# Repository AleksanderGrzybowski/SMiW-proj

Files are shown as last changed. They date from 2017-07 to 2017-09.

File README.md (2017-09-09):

# SMiW-proj
An ATmega16 based clock on steroids

This is DS1307 + ATmega based digital clock, made for Embedded Systems course. Developed on mega16 at the university (cause everyone were using mega8 for no reason), switched to mega8 later.
Includes multiplexing, I2C interfacing and buttons for setting time, brightness and other settings.

In the second version I remade it to work fully on a single 18650 battery (lasts for a week or so on a cheap cell extracted from a broken powerbank), with battery voltage monitoring. USB charger module and boost module (3.7 -> 5) are glued on the backside.

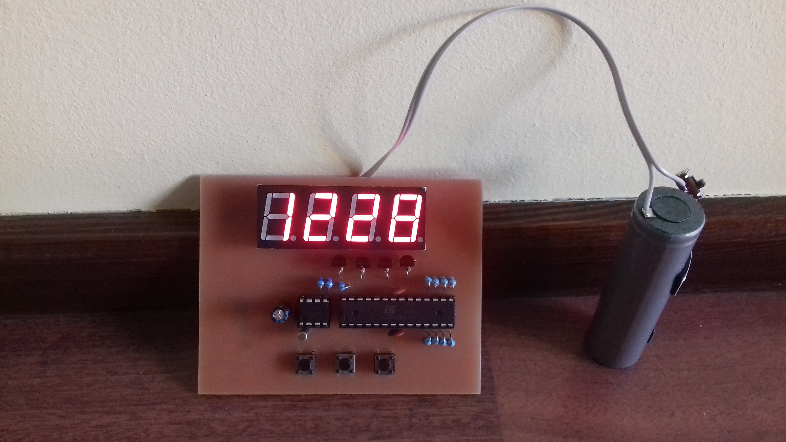
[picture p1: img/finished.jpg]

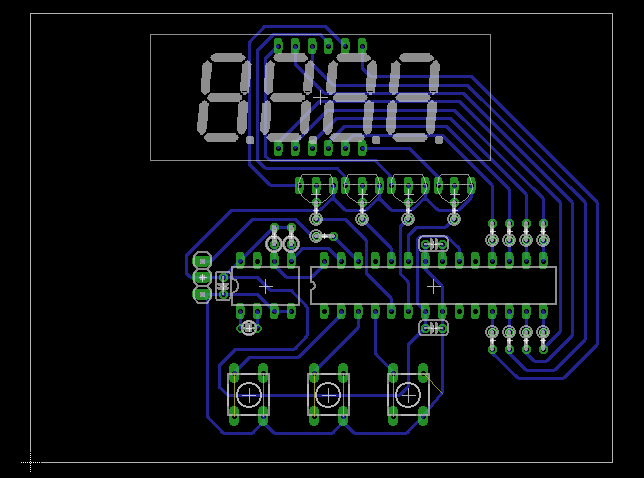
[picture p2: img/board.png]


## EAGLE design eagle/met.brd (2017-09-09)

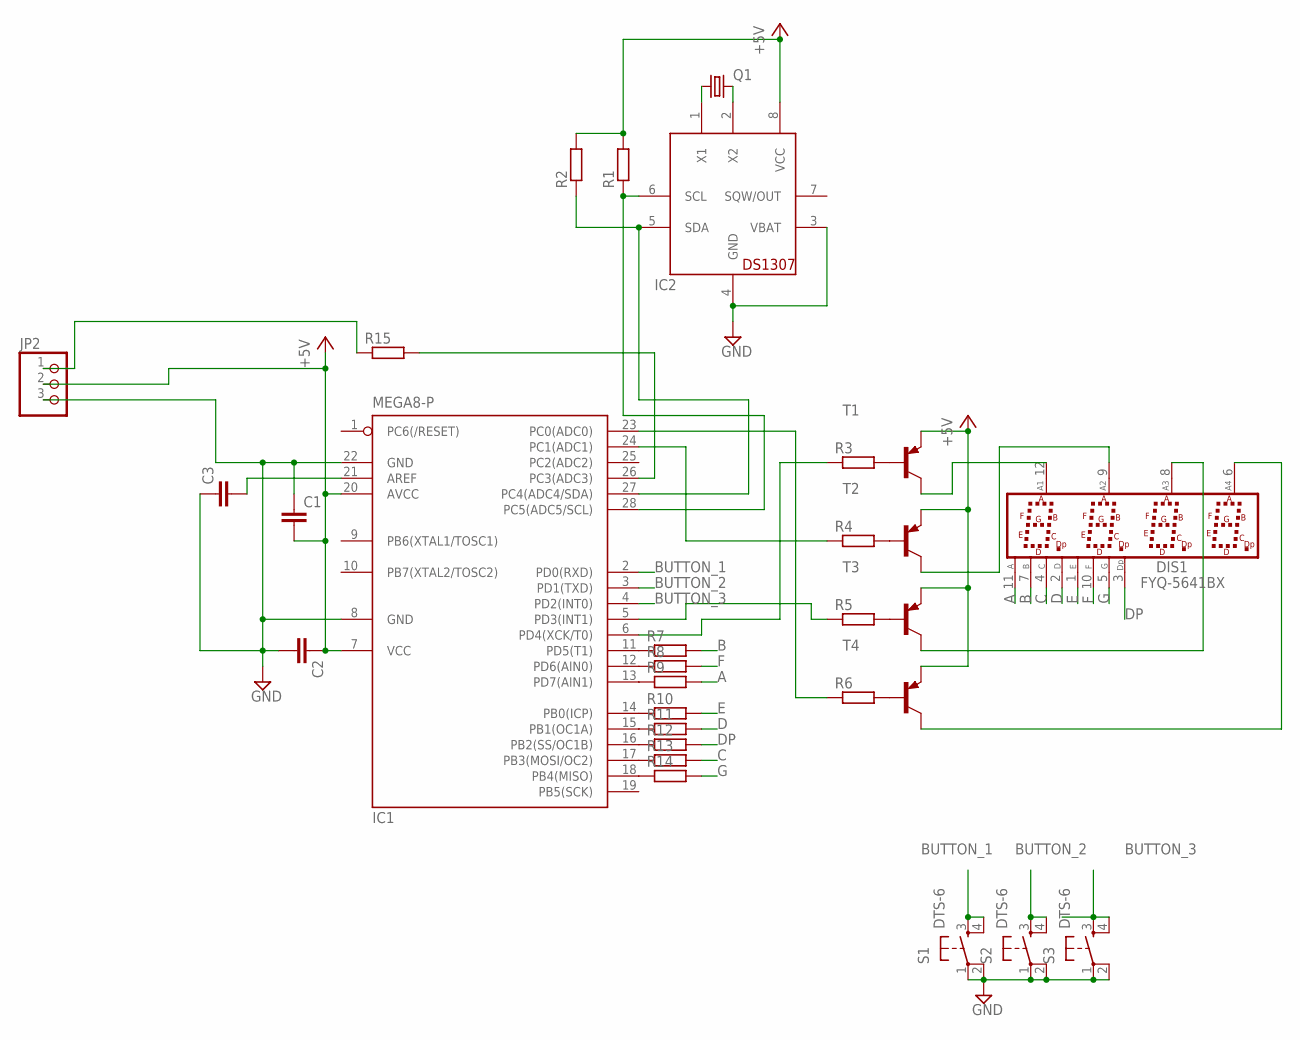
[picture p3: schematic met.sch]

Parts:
C1, C2, C3: C-EU025-024X044; C025-024X044
DIS1: FYQ-5641BX; FYQ5641
IC1: MEGA8-P; DIL28-3
IC2: DS1307; DIL08
JP2: PINHD-1X3; 1X03
Q1: CRYSTALTC26V; TC26V
R1, R2: R-EU_0207/2V; 0207/2V
R3, R4, R5, R6, R7, R8, R9, R10, R11, R12, R13, R14, R15: R-EU_0204/2V; 0204V
S1, S2, S3: DTS-6
T1, T2, T3, T4: BC327-PNP-TO92-EBC; TO92-EBC

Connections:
+5V: C1.2, C2.1, IC1.7 (VCC), IC1.20 (AVCC), IC2.8 (VCC), JP2.2, R1.2, R2.2, T1.E, T2.E, T3.E, T4.E
A: DIS1.11 (A), R9.2
B: DIS1.7 (B), R7.2
BUTTON_1: IC1.2 (PD0(RXD)), S1.3, S1.4
BUTTON_2: IC1.3 (PD1(TXD)), S2.3, S2.4
BUTTON_3: IC1.4 (PD2(INT0)), S3.3, S3.4
C: DIS1.4 (C), R13.2
D: DIS1.2 (D), R11.2
D2: DIS1.9 (A2), T2.C
D3: DIS1.8 (A3), T3.C
DOT: IC1.27 (PC4(ADC4/SDA)), IC2.5 (SDA), R2.1
DP: DIS1.3 (DP), R12.2
E: DIS1.1 (E), R10.2
F: DIS1.10 (F), R8.2
G: DIS1.5 (G), R14.2
GND: C1.1, C2.2, C3.1, IC1.8 (GND), IC1.22 (GND), IC2.3 (VBAT), IC2.4 (GND), JP2.3, S1.1, S1.2, S2.1, S2.2, S3.1, S3.2
unnamed: IC2.1 (X1), Q1.1
unnamed: IC2.2 (X2), Q1.2
unnamed: C3.2, IC1.21 (AREF)
unnamed: JP2.1, R15.1
unnamed: DIS1.6 (A4), T4.C
unnamed: IC1.28 (PC5(ADC5/SCL)), IC2.6 (SCL), R1.1
unnamed: IC1.23 (PC0(ADC0)), R6.1
unnamed: IC1.6 (PD4(XCK/T0)), R3.1
unnamed: R5.2, T3.B
unnamed: R3.2, T1.B
unnamed: R4.2, T2.B
unnamed: R6.2, T4.B
unnamed: IC1.24 (PC1(ADC1)), R4.1
unnamed: IC1.5 (PD3(INT1)), R5.1
unnamed: IC1.11 (PD5(T1)), R7.1
unnamed: IC1.12 (PD6(AIN0)), R8.1
unnamed: IC1.13 (PD7(AIN1)), R9.1
unnamed: IC1.14 (PB0(ICP)), R10.1
unnamed: IC1.15 (PB1(OC1A)), R11.1
unnamed: IC1.16 (PB2(SS/OC1B)), R12.1
unnamed: IC1.17 (PB3(MOSI/OC2)), R13.1
unnamed: DIS1.12 (A1), T1.C
unnamed: IC1.18 (PB4(MISO)), R14.1
unnamed: IC1.26 (PC3(ADC3)), R15.2

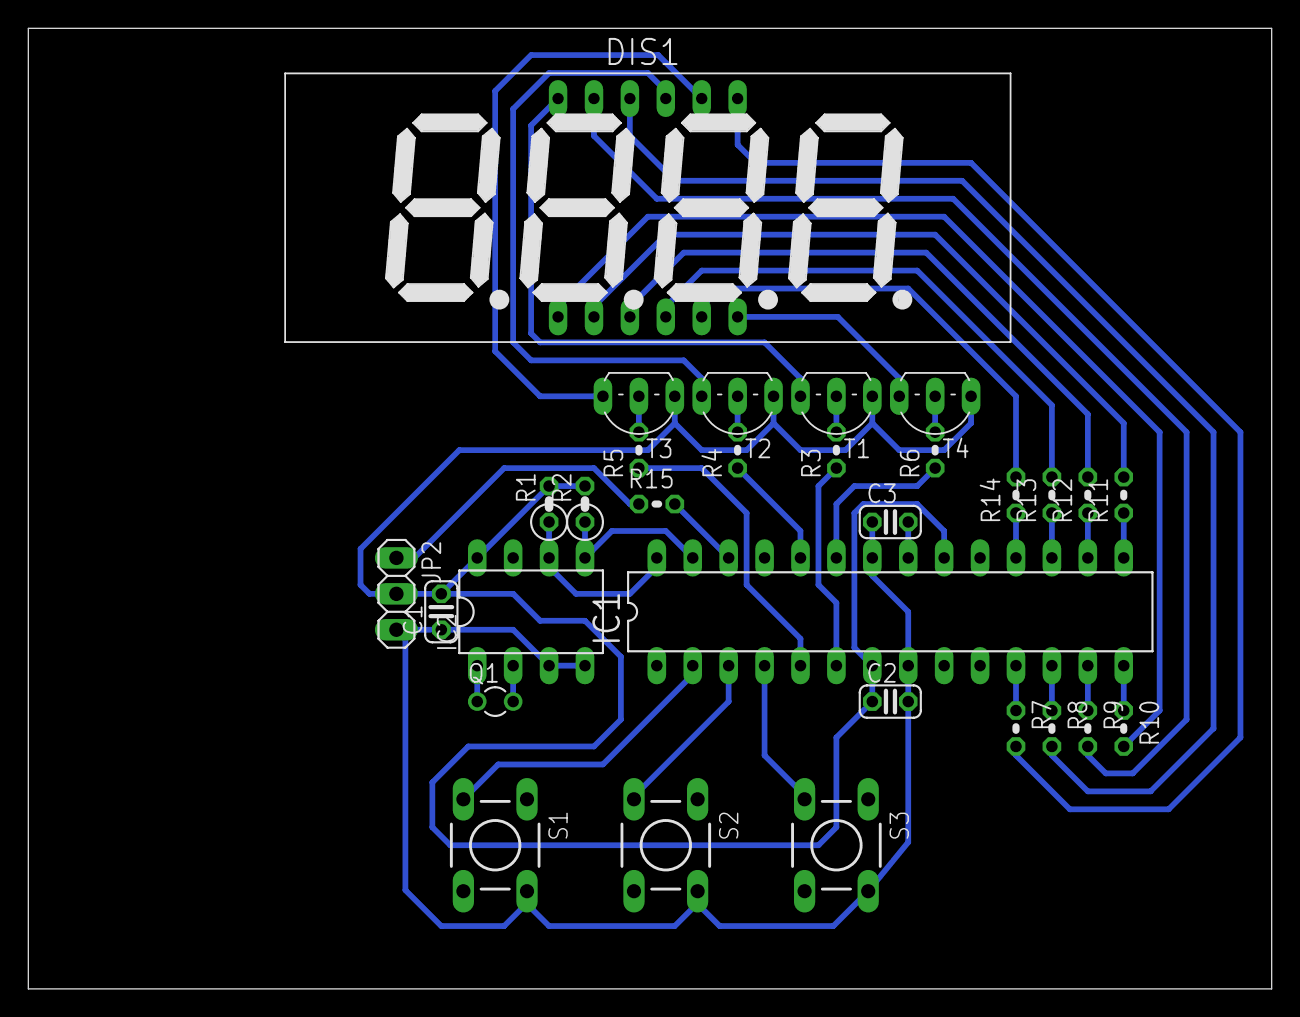
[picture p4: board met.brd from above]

Board: 2 copper layers, 87.9 x 67.9 mm, 30 parts (0 on the bottom side), 40 nets.

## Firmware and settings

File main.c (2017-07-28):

//#define F_CPU 1000000UL

#include <avr/io.h>
#include <util/delay.h>
#include <avr/interrupt.h>
#include <stdlib.h>
#include <stdio.h>
#include <avr/eeprom.h>
#include "ds1307.h"


void delay_ms(uint32_t count) {
    while (count--) {
        _delay_ms(1);
    }
}

////////////////////////////////////////////////////////

#define CONF_BUTTON_SETTIME_PORT PORTD
#define CONF_BUTTON_SETTIME_DDR  DDRD
#define CONF_BUTTON_SETTIME_PIN  PIND
#define CONF_BUTTON_SETTIME_NUM  1

#define CONF_BUTTON_DOWN_PORT PORTD
#define CONF_BUTTON_DOWN_DDR  DDRD
#define CONF_BUTTON_DOWN_PIN  PIND
#define CONF_BUTTON_DOWN_NUM  0

#define CONF_BUTTON_UP_PORT PORTD
#define CONF_BUTTON_UP_DDR  DDRD
#define CONF_BUTTON_UP_PIN  PIND
#define CONF_BUTTON_UP_NUM  2

/////////////////////////////////////////////////////

#define DOT 128
#define G 64
#define F 32
#define E 16
#define D 8
#define C 4
#define B 2
#define A 1

char tab[26] = {
    (A + B + C + D + E + F),
    (B + C),
    (A + B + G + E + D),
    (A + B + G + C + D),
    (F + G + B + C),
    (A + F + G + C + D),
    (A + F + G + E + D + C),
    (F + A + B + C),
    (A + B + C + D + E + F + G),
    (A + B + C + D + F + G),
    (B),
    (0),
    (A + C + D + F + G),
    (A + D + E + F + G),
    (D + E + F + G),
    (A + B + E + F + G),
    (C + E + G),
    (A + E + F + G),
    (A + B + C + E + F + G),
    (D + E + F),
    (B + C + D + E + G),
    (A + F + E + D),
    (B + C + D + E + F),
    (E + G),
    (E + F + G + B + C),
    (C + D + E)
};

#define LETTER_I 1
#define LETTER_O 0
#define DASH 10
#define EMPTY_DIGIT 11
#define LETTER_S 12
#define LETTER_E 13
#define LETTER_T 14
#define LETTER_P 15
#define LETTER_M 16
#define LETTER_N 16
#define LETTER_F 17
#define LETTER_A 18
#define LETTER_L 19
#define LETTER_D 20
#define LETTER_C 21
#define LETTER_U 22
#define LETTER_R 23
#define LETTER_H 24
#define LETTER_W 25

/////////////////////////////////////////////////////
#define BATTERY_ADC_CHANNEL 3

#define MAX_PWM_BRIGHTNESS 12
#define NIGHT_BRIGHTNESS 1

// 370 means 3.70V - easy format for displaying
volatile uint16_t battery_alarm_threshold = 350;

volatile uint8_t display[4];
volatile uint8_t dot_on = 0;
volatile uint8_t brightness = MAX_PWM_BRIGHTNESS / 2;
volatile uint8_t is_night = 0;

/* variables for PWM and switching digits */
volatile uint8_t pwm_iter = 0;
volatile uint8_t current_digit = 0; // current displayed digit

ISR(TIMER0_OVF_vect) {

    /* regulate speed of multiplexing, less = slower
     * this is way simpler than fiddling with prescalers :)
     */
    TCNT0 = 250;

    pwm_iter++;
    if (pwm_iter == MAX_PWM_BRIGHTNESS) {
        pwm_iter = 0;
        current_digit++;
    }
    if (current_digit == 4) {
        current_digit = 0;
    }

    /* prevent ghosting */
    PORTB |= (1 << PB0) | (1 << PB1) | (1 << PB2) | (1 << PB3) | (1 << PB4);
    PORTD |= (1 << PD5) | (1 << PD6) | (1 << PD7);

    PORTC |= (1 << PC0) | (1 << PC1);
    PORTD |= (1 << PD3) | (1 << PD4);

    /* turn on/off current digit, based on pwm current value */
    int real_brightness = is_night ? NIGHT_BRIGHTNESS : brightness;
    if (pwm_iter < real_brightness) {
        if (current_digit == 3) {
            PORTC &= ~(1 << PC0);
        }
        if (current_digit == 1) {
            PORTC &= ~(1 << PC1);
        }
        if (current_digit == 2) {
            PORTD &= ~(1 << PD3);
        }
        if (current_digit == 0) {
            PORTD &= ~(1 << PD4);
        }
    } 

    /* select segments */
    uint8_t value = ~tab[display[current_digit]];

    if (value & 1) {
        PORTD |= (1 << PD7);
    } else {
        PORTD &= ~(1 << PD7);
    }
    if (value & 2) {
        PORTD |= (1 << PD5);
    } else {
        PORTD &= ~(1 << PD5);
    }
    if (value & 4) {
        PORTB |= (1 << PB3);
    } else {
        PORTB &= ~(1 << PB3);
    }
    if (value & 8) {
        PORTB |= (1 << PB1);
    } else {
        PORTB &= ~(1 << PB1);
    }
    if (value & 16) {
        PORTB |= (1 << PB0);
    } else {
        PORTB &= ~(1 << PB0);
    }
    if (value & 32) {
        PORTD |= (1 << PD6);
    } else {
        PORTD &= ~(1 << PD6);
    }
    if (value & 64) {
        PORTB |= (1 << PB4);
    } else {
        PORTB &= ~(1 << PB4);
    }
    if (current_digit == 1 && dot_on) {
        PORTB &= ~(1 << PB2);
    } else {
        PORTB |= (1 << PB2);
    }
}

void adc_init() {
    // AREF = AVcc
    ADMUX = (1 << REFS0);
 
    // 128 prescaler
    ADCSRA = (1 << ADEN) | (1 << ADPS2) | (1 << ADPS1) | (1 << ADPS0);
}

uint16_t adc_read(uint8_t ch) {
    ch &= 0b00000111;
    ADMUX = (ADMUX & 0xF8) | ch;
    ADCSRA |= (1 << ADSC);
 
    while (ADCSRA & (1 << ADSC));
    return ADC;
}

#define ADC_SAMPLES 50
#define ADC_SAMPLING_DELAY_MS 10
#define ADC_VREF 5.0

uint16_t current_battery_voltage() { // if 3.8V -> return 380
    uint8_t i;
    uint16_t sum = 0;

    for (i = 0; i < ADC_SAMPLES; ++i) {
        sum += adc_read(BATTERY_ADC_CHANNEL);
        _delay_ms(ADC_SAMPLING_DELAY_MS);
    }

    uint16_t battery_mv = (uint16_t) (sum * ADC_VREF * 1000.0 / (1024.0 * ADC_SAMPLES));
    return battery_mv / 10;
}

/* set display's digits, each digit separately, useful for debugging and used by other funcs */
void set_display_each_digit(uint8_t dig0, uint8_t dig1, uint8_t dig2, uint8_t dig3, uint8_t dot) {
    display[0] = dig0;
    display[1] = dig1;
    display[2] = dig2;
    display[3] = dig3;
    dot_on = dot;
}

/* set display's digits, two numbers in range <0..99> without leading '0'
 * if given -1, it will display empty digit (no segments lit)
 */
void set_display_two_digits(int8_t left, int8_t right, int8_t dot) {
    uint8_t dig0, dig1, dig2, dig3;
    if (left == -1) {
        dig0 = EMPTY_DIGIT;
        dig1 = EMPTY_DIGIT;
    } else {
        dig0 = ((left / 10) == 0 ? EMPTY_DIGIT : (left / 10)); // without leading '0'
        dig1 = left % 10;
    }

    if (right == -1) {
        dig2 = EMPTY_DIGIT;
        dig3 = EMPTY_DIGIT;
    } else {
        dig2 = right / 10;
        dig3 = right % 10;
    }

    set_display_each_digit(dig0, dig1, dig2, dig3, dot);
}

/* set display's digits, one number in range <0.9999>, great for debug */
void set_display_whole_number(uint16_t number, uint8_t dot) {
    uint8_t d3 = number % 10;
    number /= 10;
    uint8_t d2 = number % 10;
    number /= 10;
    uint8_t d1 = number % 10;
    number /= 10;
    uint8_t d0 = number % 10;

    if (d0 == 0) {
        d0 = EMPTY_DIGIT;
        if (d1 == 0) {
            d1 = EMPTY_DIGIT;
            if (d2 == 0) {
                d2 = EMPTY_DIGIT;
            }
        }
    }

    set_display_each_digit(d0, d1, d2, d3, dot);
}

/* display current time */
void disp_time_and_update_night_status() {
    uint8_t hour, minute, second, dummy;
    ds1307_getdate(&dummy, &dummy, &dummy, &hour, &minute, &second);

    set_display_two_digits(hour, minute, (second % 2 == 1));
    is_night = (hour >= 0 && hour <= 4);
}

/* ask user to input time */
#define DEBOUNCE_DELAY 100 // ms
void get_time_from_user(uint8_t hour, uint8_t minute, uint8_t* out_hour, uint8_t* out_minute) {

    int blink = 0;

    while (CONF_BUTTON_SETTIME_PIN & _BV(CONF_BUTTON_SETTIME_NUM)) { // wait for hours
        delay_ms(DEBOUNCE_DELAY);
        if (!(CONF_BUTTON_UP_PIN & _BV(CONF_BUTTON_UP_NUM))) {
            hour++;
            if (hour == 24) {
                hour = 0;
            }
            delay_ms(DEBOUNCE_DELAY);
        }
        if (!(CONF_BUTTON_DOWN_PIN & _BV(CONF_BUTTON_DOWN_NUM))) {
            if (hour == 0) {
                hour = 23;
            } else {
                hour--;
            }

            delay_ms(DEBOUNCE_DELAY);
        }
        if (blink >= 2) {
            set_display_two_digits(hour, minute, 1);
        } else {
            set_display_two_digits(-1, minute, 1);
        }

        blink++;
        if (blink == 4) {
            blink = 0;
        }
    }
    delay_ms(DEBOUNCE_DELAY);

    while (CONF_BUTTON_SETTIME_PIN & _BV(CONF_BUTTON_SETTIME_NUM)) { // wait for minutes
        delay_ms(DEBOUNCE_DELAY);
        if (!(CONF_BUTTON_UP_PIN & _BV(CONF_BUTTON_UP_NUM))) {
            minute++;
            if (minute == 60)
                minute = 0;
            delay_ms(DEBOUNCE_DELAY);
        }
        if (!(CONF_BUTTON_DOWN_PIN & _BV(CONF_BUTTON_DOWN_NUM))) {
            if (minute == 0) {
                minute = 59;
            } else {
                minute--;
            }
            delay_ms(DEBOUNCE_DELAY);
        }
        if (blink >= 2)
            set_display_two_digits(hour, minute, 1);
        else
            set_display_two_digits(hour, -1, 1);
        blink++;
        if (blink == 4)
            blink = 0;
    }

    delay_ms(DEBOUNCE_DELAY);

    *out_hour = hour;
    *out_minute = minute;
}

void get_brightness_from_user() {
    set_display_each_digit(LETTER_D, 1, LETTER_S, LETTER_P, 0); // DISP

    while (CONF_BUTTON_SETTIME_PIN & _BV(CONF_BUTTON_SETTIME_NUM)) { // wait for hours
        delay_ms(DEBOUNCE_DELAY);
        if (!(CONF_BUTTON_UP_PIN & _BV(CONF_BUTTON_UP_NUM))) {
            if (brightness < (MAX_PWM_BRIGHTNESS - 1)) {
                brightness++;
            }
            delay_ms(DEBOUNCE_DELAY);
        }
        if (!(CONF_BUTTON_DOWN_PIN & _BV(CONF_BUTTON_DOWN_NUM))) {
            if (brightness > 1) {
                brightness--;
            }
            delay_ms(DEBOUNCE_DELAY);
        }
    }
    delay_ms(DEBOUNCE_DELAY);
}

void show_current_battery_voltage_to_user() {
    set_display_each_digit(LETTER_C, LETTER_U, LETTER_R, LETTER_R, 0);
    delay_ms(1000);

    while (CONF_BUTTON_SETTIME_PIN & _BV(CONF_BUTTON_SETTIME_NUM)) { 
        delay_ms(DEBOUNCE_DELAY);
        uint16_t current_voltage = current_battery_voltage();
        set_display_whole_number(current_voltage, 1);
    }
}

void get_threshold_battery_from_user() {
    set_display_each_digit(LETTER_T, LETTER_H, LETTER_R, LETTER_S, 0);
    delay_ms(1000);

    int blink = 0;

    while (CONF_BUTTON_SETTIME_PIN & _BV(CONF_BUTTON_SETTIME_NUM)) {
        delay_ms(DEBOUNCE_DELAY);
        if (!(CONF_BUTTON_UP_PIN & _BV(CONF_BUTTON_UP_NUM))) {
            battery_alarm_threshold++;
            delay_ms(DEBOUNCE_DELAY);
        }
        if (!(CONF_BUTTON_DOWN_PIN & _BV(CONF_BUTTON_DOWN_NUM))) {
            battery_alarm_threshold--;
            delay_ms(DEBOUNCE_DELAY);
        }

        blink = !blink;
        if (blink) {
            set_display_whole_number(battery_alarm_threshold, 1);
        } else {
            set_display_two_digits(-1, -1, 1);
        }
    }

    delay_ms(DEBOUNCE_DELAY);
}

/* ask user for time and set it as current time */
void set_time() {
    uint8_t dummy;
    uint8_t hour = 0;
    uint8_t minute = 0;

    set_display_each_digit(LETTER_S, LETTER_E, LETTER_T, EMPTY_DIGIT, 0);
    delay_ms(500);
    ds1307_getdate(&dummy, &dummy, &dummy, &hour, &minute, &dummy);

    uint8_t new_hour, new_minute;
    get_time_from_user(hour, minute, &new_hour, &new_minute);
    ds1307_setdate(1, 1, 1, new_hour, new_minute, 0);
}

int main() {

    /* set all pins as inputs with pullups, so accidental short is not a problem */
    DDRB = DDRC = DDRD = 0x00;
    PORTB = PORTC = PORTD = 0xff;

    /* enable timer overflow interrupts for PWM */
    TIMSK |= (1 << TOIE0);
    TCCR0 &= ~(1 << CS02);
    TCCR0 |= (1 << CS01);
    TCCR0 |= (1 << CS00);
    sei();

    /* display outputs */
    DDRC |= (1 << PC0) | (1 << PC1);
    DDRD |= (1 << PD3) | (1 << PD4);
    DDRB |= (1 << PB0) | (1 << PB1) | (1 << PB2) | (1 << PB3) | (1 << PB4);
    DDRD |= (1 << PD5) | (1 << PD6) | (1 << PD7);

    /* buttons inputs */
    CONF_BUTTON_SETTIME_DDR &= ~_BV(CONF_BUTTON_SETTIME_NUM);
    CONF_BUTTON_SETTIME_PORT |= _BV(CONF_BUTTON_SETTIME_NUM);

    CONF_BUTTON_UP_DDR &= ~_BV(CONF_BUTTON_UP_NUM);
    CONF_BUTTON_UP_PORT |= _BV(CONF_BUTTON_UP_NUM);

    CONF_BUTTON_DOWN_DDR &= ~_BV(CONF_BUTTON_DOWN_NUM);
    CONF_BUTTON_DOWN_PORT |= _BV(CONF_BUTTON_DOWN_NUM);


    // ADC input
    DDRC &= ~(1 << PC3);
    PORTC &= ~(1 << PC3);
    adc_init();

    /* start RTC and check if it ticks, it might be stuck on cold start, 
     * so to force start, simply set any hour
    */
    ds1307_init();
    uint8_t dummy, hour, minute, second;
    ds1307_getdate(&dummy, &dummy, &dummy, &hour, &minute, &second);
    if (hour == 0 && minute == 0 && second == 0) {
        ds1307_setdate(1, 1, 1, 0, 0, 0);
        set_display_each_digit(DASH, DASH, DASH, DASH, 1);
        delay_ms(2000);
    }

#define UPDATE_INTERVAL_TIME 200
#define BATTERY_LOW_MESSAGE_TIME 1000L * 10 // 10 seconds
#define BATTERY_CHECK_INTERVAL (1000 / UPDATE_INTERVAL_TIME) * 60 // check every minute

    uint16_t battery_check_counter = 0;

    while (1) {
        disp_time_and_update_night_status();
        delay_ms(UPDATE_INTERVAL_TIME);

        if (!(CONF_BUTTON_SETTIME_PIN & _BV(CONF_BUTTON_SETTIME_NUM))) {
            set_time();
            get_brightness_from_user();
            show_current_battery_voltage_to_user();
            get_threshold_battery_from_user();
        }

        battery_check_counter++;
        if (battery_check_counter == BATTERY_CHECK_INTERVAL) {
            battery_check_counter = 0;
            if (current_battery_voltage() < battery_alarm_threshold) {
                set_display_each_digit(LETTER_L, 0, LETTER_W, EMPTY_DIGIT, 0);
                delay_ms(BATTERY_LOW_MESSAGE_TIME);
            }
        }
    }
}

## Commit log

2014-11-13 Simple soft PWM
2014-11-13 Replaced old ds18b20 lib with working one, lol
    [main.c]
2014-11-13 Moved 7seg abcdefgD to PORTD, so we can use ADC later
2014-11-13 Added buttons to set current time
2014-11-13 Added phototransistor and working ADC displaying
2014-11-19 Buttons to show temp/light, no auto
2014-11-20 Add stub implementation of light-sensed pwm
2014-11-26 Alarm of is '0', on is '1' - added buzzer so needed to change
    [main.c]
2014-11-26 Read temperature less often
2014-12-06 Remove "INIT" on start, turn off pnp-s while switching digits
2015-06-29 Removed unneeded features (alarm/buzzer/photo/adc)
    [main.c]
2015-07-05 Remove temperature reading
2015-07-07 Fixed ghosting (took me 2 hours to find out lol)
    [main.c]
2016-12-18 Adjust code to the new board layout
2017-01-17 Final board and photos
    [clk.brd, clk.sch]
2017-07-27 Port to ATmega8, hacking around strange issue
    [main.c]
2017-07-27 FML fix ghosting finally
    [main.c]
2017-07-28 Measuring and selecting threshold voltage
2017-07-28 Add battery monitoring
2017-07-28 12 PWM levels
2017-07-28 Show 'low battery' for longer time
2017-09-09 Finished and tested version 2
    [clk.brd, clk.sch]
2017-11-18 Back up Eagle files
    [met.brd, met.sch]
